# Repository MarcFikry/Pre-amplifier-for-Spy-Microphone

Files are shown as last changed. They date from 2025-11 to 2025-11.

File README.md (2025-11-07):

# Pre-amplifier for Spy Microphone 

## Project Overview
This project was carried out as part of the **1A Bureau d'Étude d'Électronique (Electronics Design Project)** at **Grenoble INP – Phelma**, during the first semester of the **Physics, Electronics and Telecommunications (PET)** engineering program.

The objective was to design and implement a **pre-amplifier for an electret microphone**, which could be later connected to an FM transmitter.  
Which includes the following functional blocks:
- Microphone biasing and pre-amplification
- Adjustable volume control
- Sound detection via a LED indicator

All circuits were powered under **asymmetrical supply (0–5 V)** and implemented using **MCP6002 operational amplifiers**.

---

## Features
- **Electret Microphone Biasing** — converts the small current variations from the microphone into voltage.  
- **Variable Gain Amplifier** — amplifies weak audio signals with adjustable sensitivity.  
- **Volume Control** — allows amplitude adjustment before the output stage to avoid distortion.  
- **Sound Detection LED** — implemented with a comparator with hysteresis to indicate when a sound is detected.  
- **Power Supply:** 0 – 5 V (single supply)  

---

## Design and Implementation
- Circuit **designed and simulated in KiCad**
- **Component sizing** based on theoretical transfer functions and Bode plots  
- **PCB routing** performed in KiCad, ensuring clean signal paths and proper grounding  
- **PCB manufacturing** followed by **manual soldering** and **experimental validation**  
- Tested using **oscilloscope** and **function generator** to verify:
  - Correct biasing
  - Amplification gain and frequency response
  - Proper LED threshold behavior

---

## Project Images

### Schematic Diagram  


### PCB Layout (Design in KiCad)  


### Printed PCB (Before Soldering)  
WhatsApp Image 2025-11-07 à 00 43 34_8c52c60e

### Assembled Board (After Soldering)  
WhatsApp Image 2025-11-07 à 00 43 34_da2ad6b6

---

## Components Used
| Component | Description | Note |
|---|---|---|
| MCP6002 | Dual Operational Amplifier | 0–5 V single-supply compatible |
| Electret Microphone | Audio input sensor | Requires biasing resistor |
| Resistors / Potentiometers | Gain and volume adjustment | E12 standard series |
| LED + Comparator | Sound level indicator | Implemented with hysteresis |
| Capacitors | AC coupling and filtering | 50 Hz–20 kHz bandpass design |

---

## Results
- Clean and stable amplification of the audio signal  
- Adjustable output amplitude via volume potentiometer  
- Reliable LED indication of detected sound  
- Measured gain and frequency response consistent with theoretical predictions  

---

## Tools and Environment
- **Software:** KiCad, Oscilloscope interface tools  
- **Hardware:** Breadboard, 0–5 V power supply, Function generator   

---

## Acknowledgments
Project supervised by:
- **Nicolas Ruty**
- **Fanny Poinsotte**
- **Matthieu Guerquin-Kern**

Grenoble INP – Phelma, 1A PET (Tronc Commun)

---

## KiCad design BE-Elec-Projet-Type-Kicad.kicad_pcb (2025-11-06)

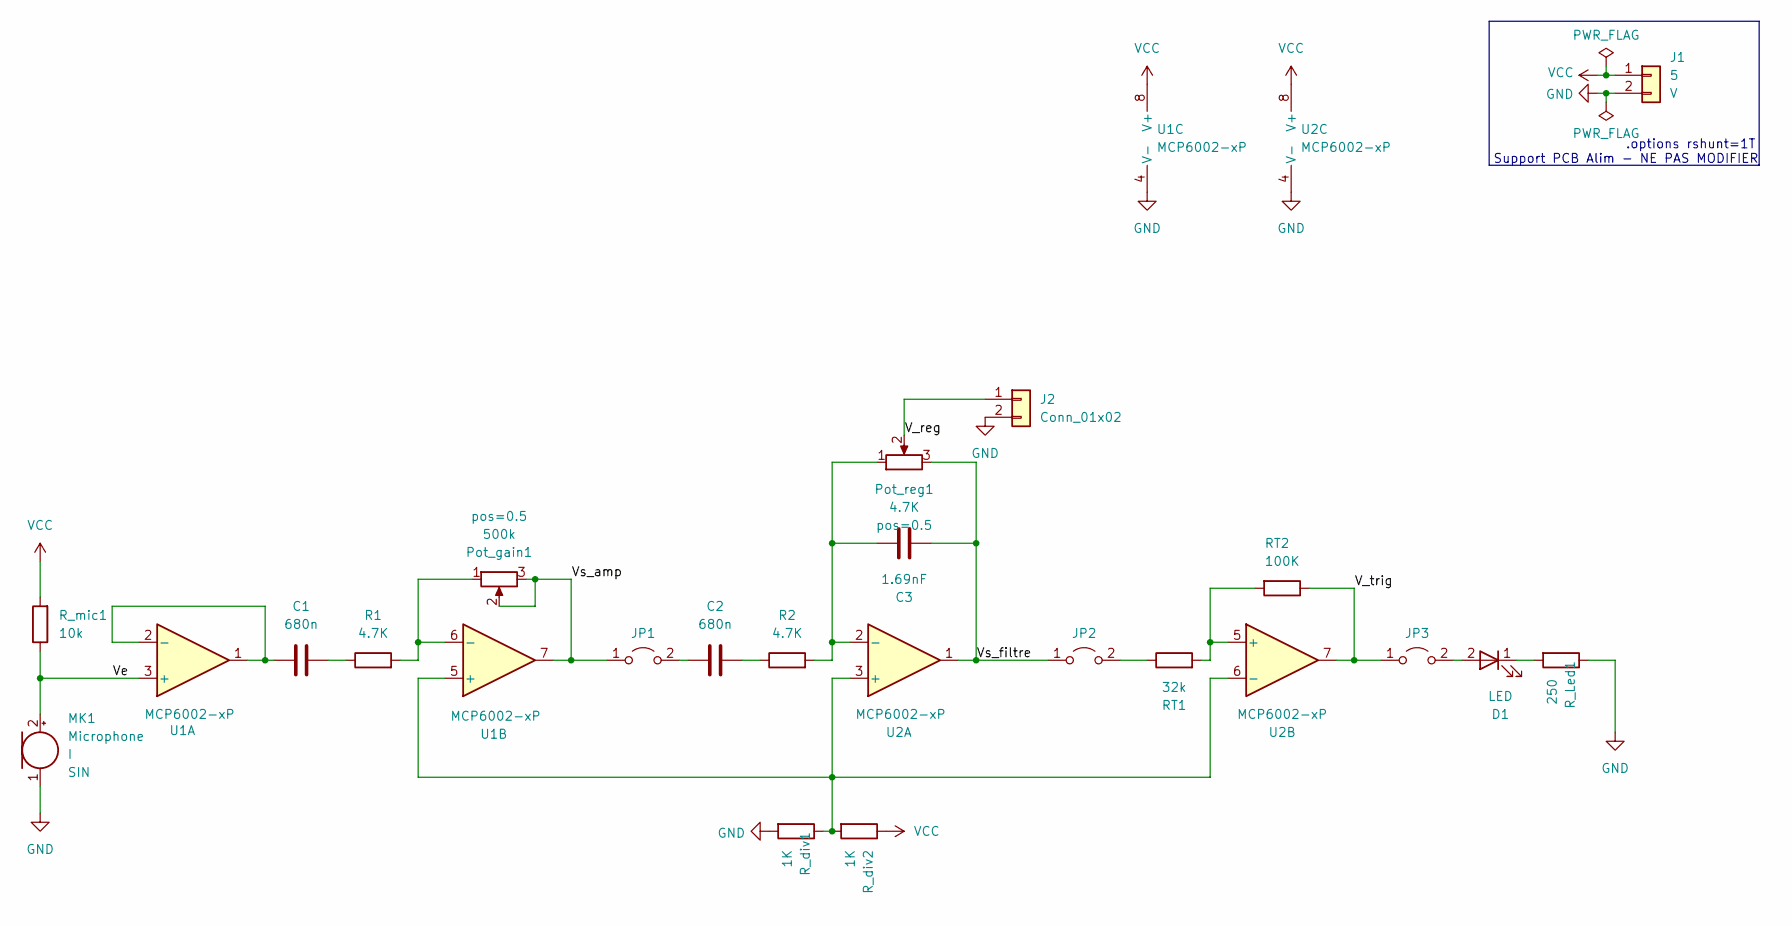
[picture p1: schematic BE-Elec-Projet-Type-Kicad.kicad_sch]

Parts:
C1, C2: 680n; CONDENSATEUR_5.08MM
C3: 1.69nF; CONDENSATEUR_5.08MM
D1: LED; LED_D5.0mm
J1: 5; PinHeader_1x02_P2.54mm_Vertical
J2: Conn_01x02; PinHeader_1x02_P2.54mm_Vertical
JP1, JP2, JP3: 1m; PinHeader_1x02_P2.54mm_Vertical
MK1: Microphone; PinHeader_1x02_P2.54mm_Vertical
Pot_gain1: 500k; Potentiometer_Piher_PT-10-V10_Vertical
Pot_reg1: 4.7K; Potentiometer_Piher_PT-10-V10_Vertical
R1, R2: 4.7K; R_Axial_DIN0207_L6.3mm_D2.5mm_P10.16mm_Horizontal
RT1: 32k; R_Axial_DIN0207_L6.3mm_D2.5mm_P10.16mm_Horizontal
RT2: 100K; R_Axial_DIN0207_L6.3mm_D2.5mm_P10.16mm_Horizontal
R_Led1: 250; R_Axial_DIN0207_L6.3mm_D2.5mm_P10.16mm_Horizontal
R_div1, R_div2: 1K; R_Axial_DIN0207_L6.3mm_D2.5mm_P10.16mm_Horizontal
R_mic1: 10k; R_Axial_DIN0207_L6.3mm_D2.5mm_P10.16mm_Horizontal
U1, U2: MCP6002-xP; DIP-8_W7.62mm_Socket_LongPads

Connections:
/V_reg: J2.1, Pot_reg1.2
/V_trig: JP3.1 (A), RT2.1, U2.7
/Ve: MK1.2 (+), R_mic1.1, U1.3 (+)
/Vs_amp: JP1.1 (A), Pot_gain1.2, Pot_gain1.3, U1.7
/Vs_filtre: C3.2, JP2.1 (A), Pot_reg1.3, U2.1
GND: J1.2, J2.2, MK1.1 (-), R_Led1.1, R_div1.2, U1.4 (V-), U2.4 (V-)
unnamed: C1.2, R1.1
unnamed: C2.2, R2.1
unnamed: D1.2 (A), JP3.2 (B)
unnamed: D1.1 (K), R_Led1.2
unnamed: C2.1, JP1.2 (B)
unnamed: JP2.2 (B), RT1.1
unnamed: C1.1, U1.1, U1.2 (-)
unnamed: R_div1.1, R_div2.2, U1.5 (+), U2.3 (+), U2.6 (-)
unnamed: Pot_gain1.1, R1.2, U1.6 (-)
unnamed: C3.1, Pot_reg1.1, R2.2, U2.2 (-)
unnamed: RT1.2, RT2.2, U2.5 (+)
VCC: J1.1, R_div2.1, R_mic1.2, U1.8 (V+), U2.8 (V+)

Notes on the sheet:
Support PCB Alim - NE PAS MODIFIER
.options rshunt=1T

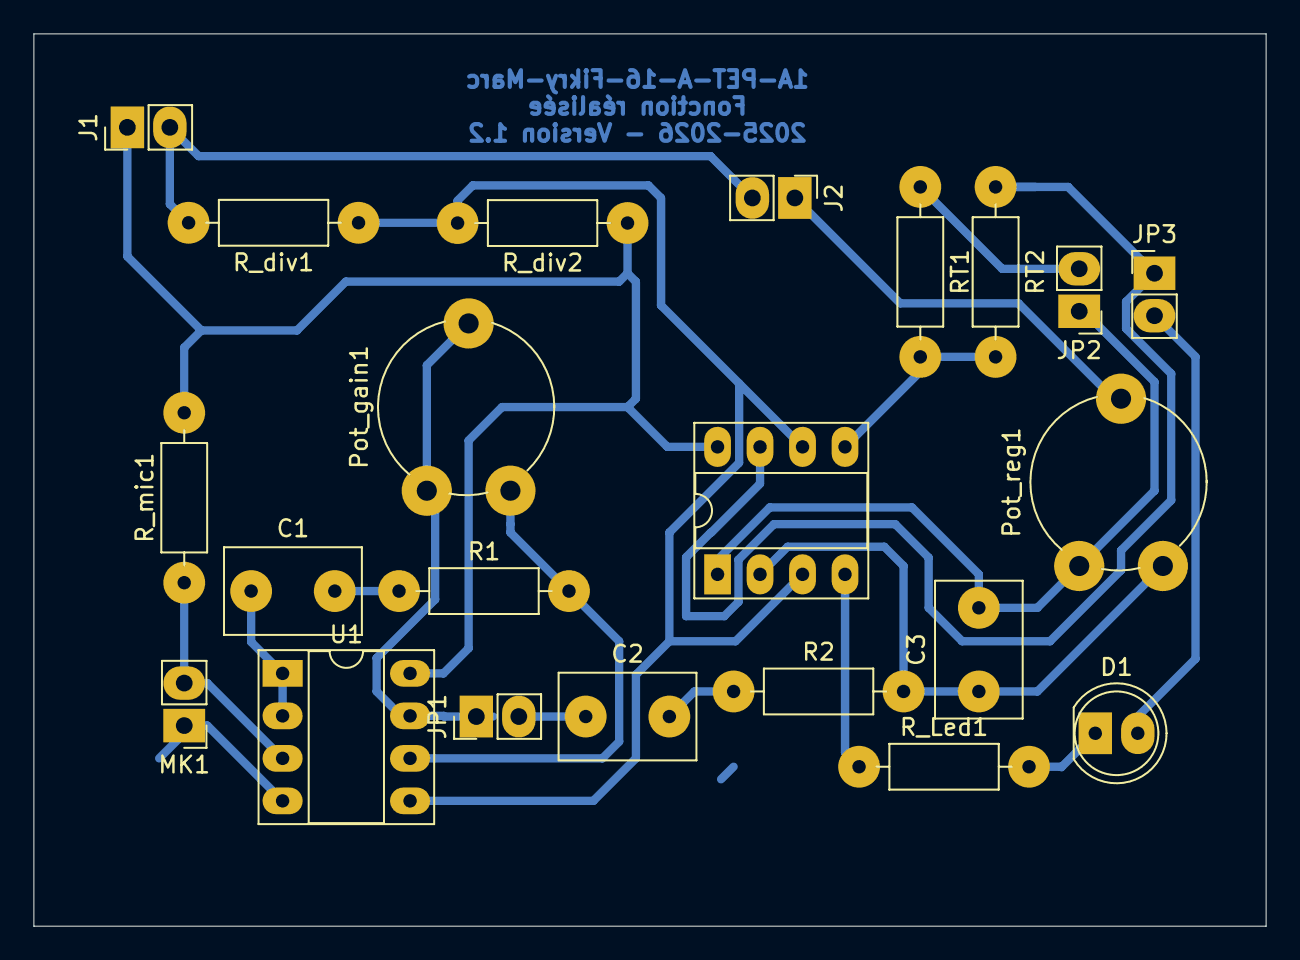
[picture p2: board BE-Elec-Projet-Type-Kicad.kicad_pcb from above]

Board: 2 copper layers, 73.7 x 53.3 mm, 22 parts (0 on the bottom side), 18 nets.
